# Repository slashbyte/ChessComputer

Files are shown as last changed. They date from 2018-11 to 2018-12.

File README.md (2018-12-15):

# PI Chess Computer
Modeled after the "Chess Challenger" made in 1978.
This PI powered, retro themed build,
is an open source hardware design capable of running an up to date chess engine, Stockfish.

## Raspberry PI Image Release
[Chess Challenger PI Image](https://github.com/slashbyte/ChessComputer-Source/releases)

### Computer Chess Clubs, BEWARE!
(Thats still a thing, right?)

<p align="center">
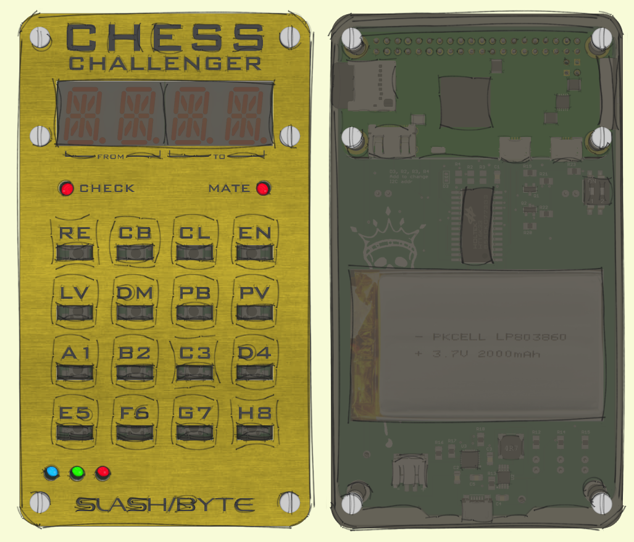
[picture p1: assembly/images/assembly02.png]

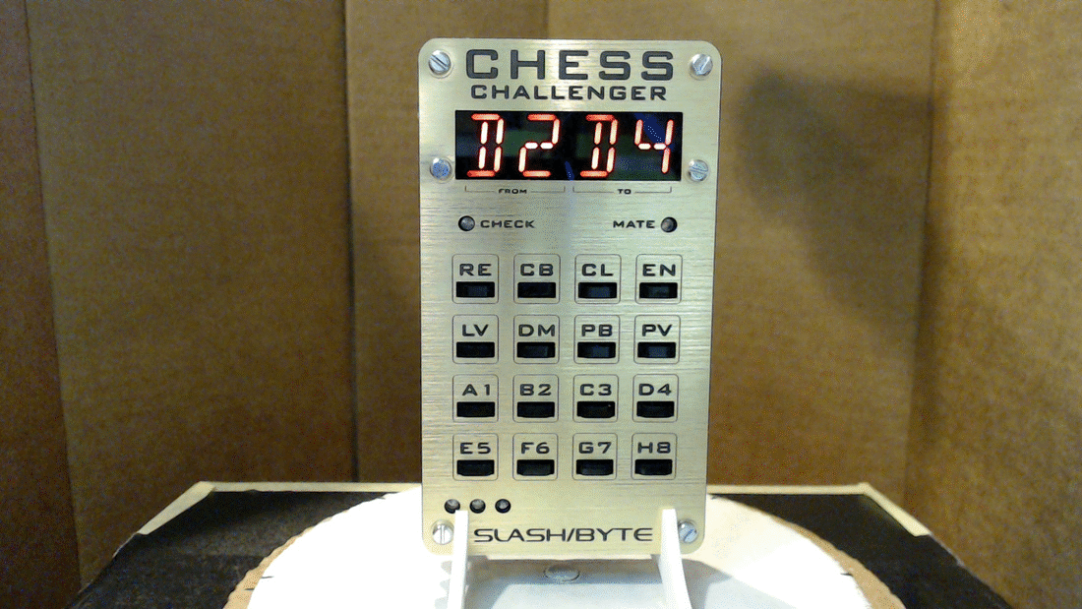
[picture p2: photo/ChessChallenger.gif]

</p>

## Authors
* **Slash/Byte** (slashqpbyte@gmail.com)
## License
This project is licensed under the MIT License
(https://opensource.org/licenses/MIT)
## Acknowledgments
* Science
* Adafruit
* Ponoko (Great fab house)
* Digikey

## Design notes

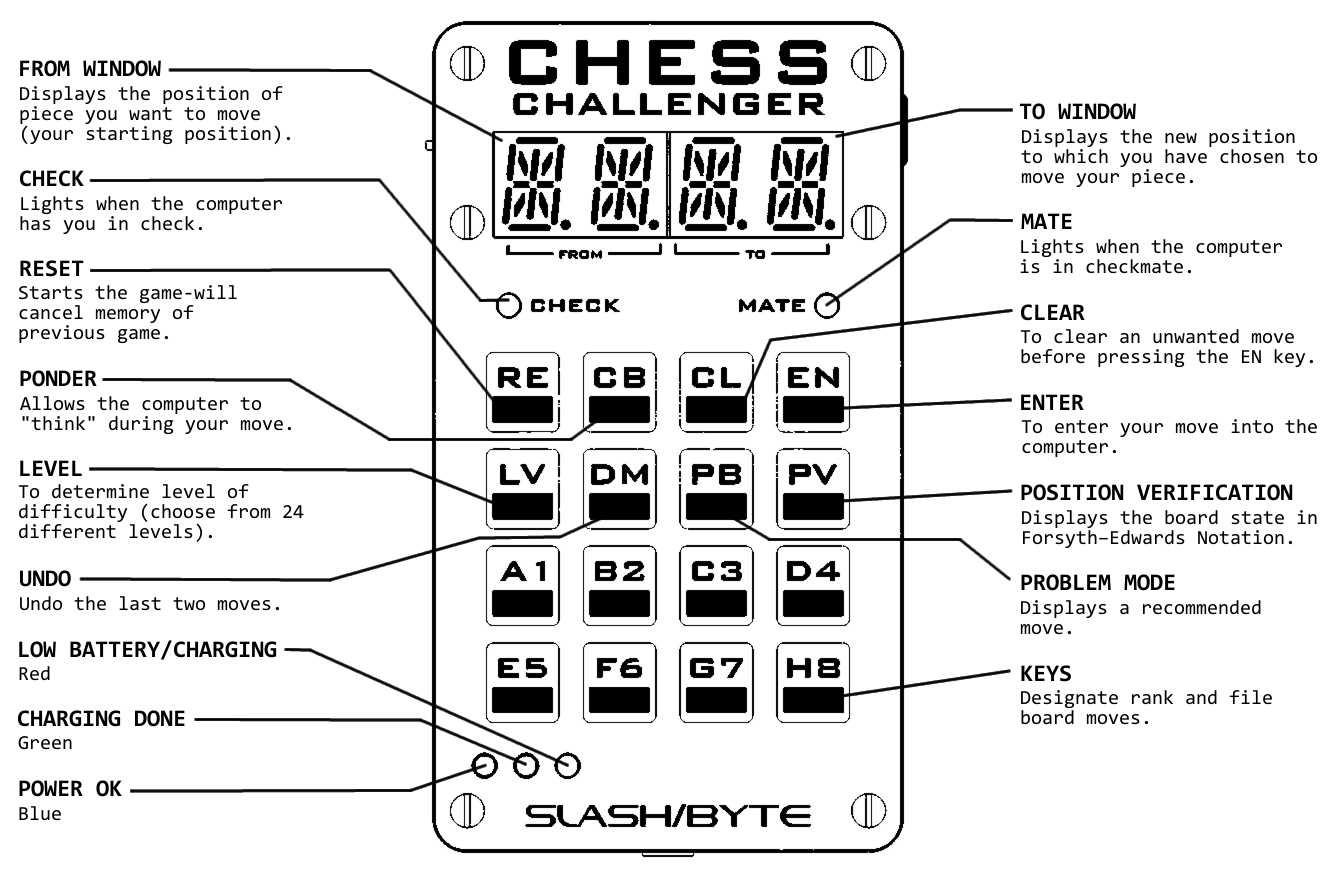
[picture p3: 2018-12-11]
wiki/photo/legned01.png

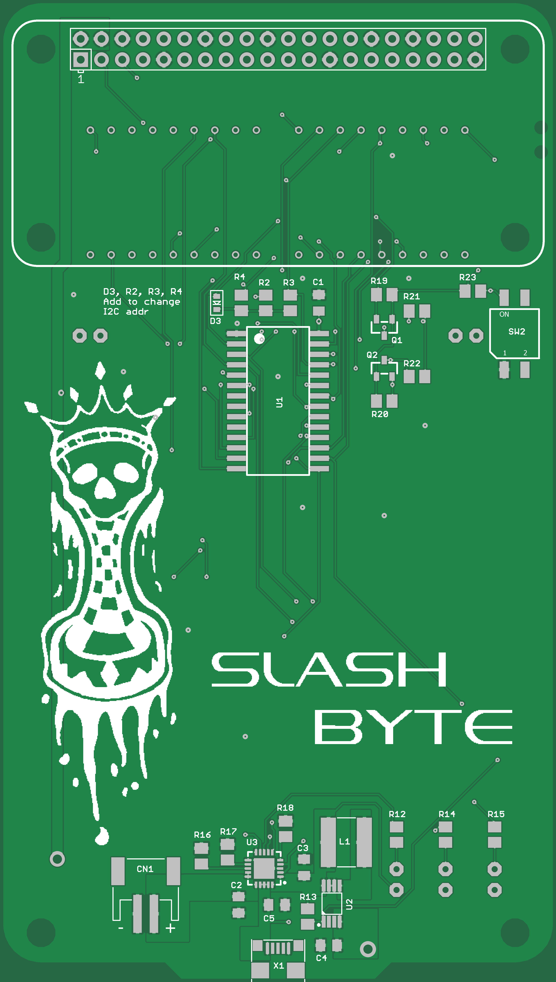
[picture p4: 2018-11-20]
board/eagleUp/eagleUp_ChessComputer_board_bottom.png

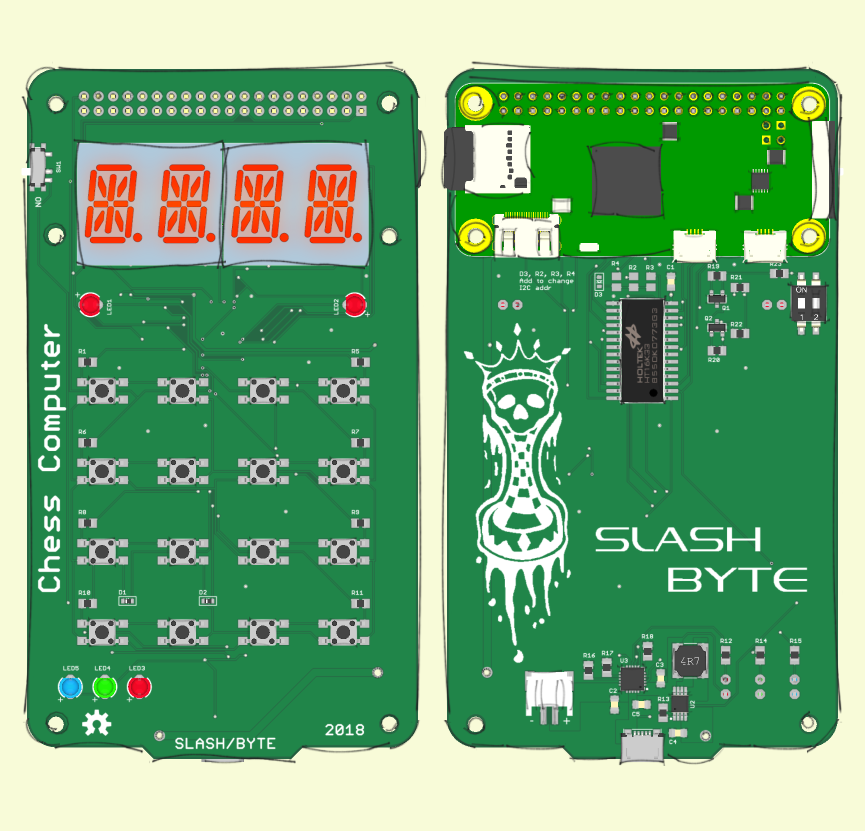
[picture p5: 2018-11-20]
3D render/image.png

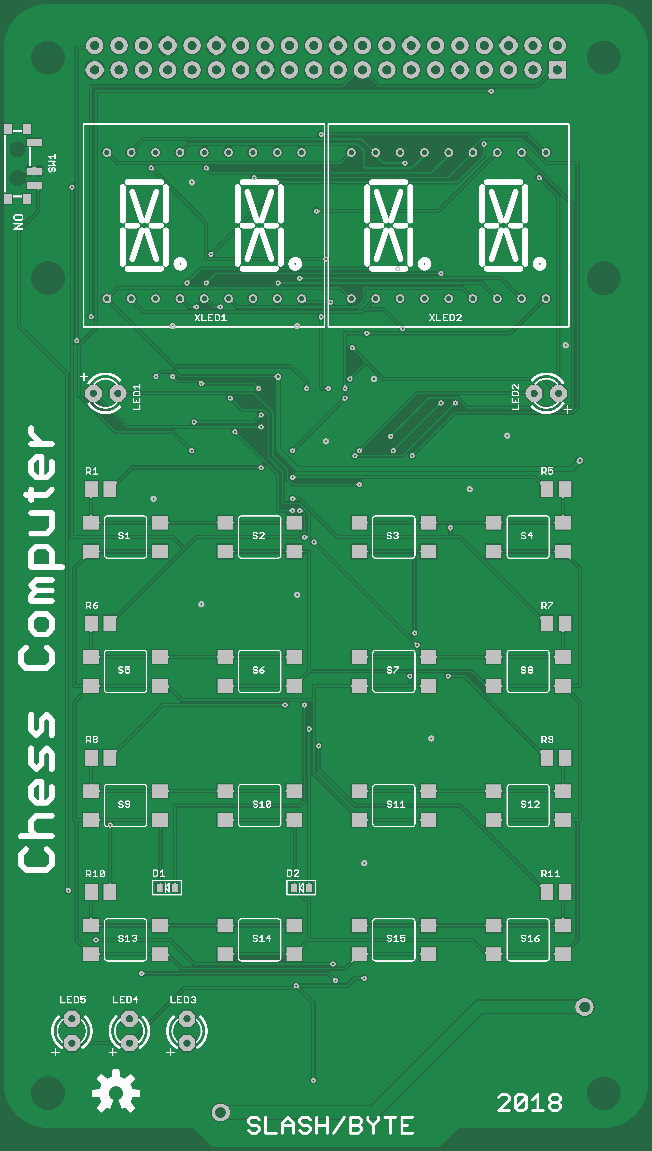
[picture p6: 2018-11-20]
board/eagleUp/eagleUp_ChessComputer_board_top.png

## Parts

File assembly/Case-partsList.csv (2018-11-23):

Index | Quantity | Digikey Part Number | Manufacturer Part Number | Description | Customer Reference
1 | 8 | RPC2275-ND | FW0045A | WASHER FLAT M2 NYLON
2 | 6 | 732-10527-ND | 970070151 | HEX SPACER M2.5X0.45 STEEL 7MM
3 | 4 | RPC4791-ND | R907-2 | ROUND SPACER NYLON 1/8"
4 | 2 | RPC4793-ND | R907-4 | ROUND SPACER NYLON 1/4"
5 | 6 | 36-29306-ND | 29306 | MACH SCREW PAN SLOTTED M2.5X0.45
6 | 6 | 36-29301-ND | 29301 | MACH SCREW PAN SLOTTED M2.5X0.45
7 | 12 | RPC1999-ND | MFW020A | WASHER FLAT M2.5 NYLON | Extra

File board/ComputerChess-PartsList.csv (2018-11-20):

Qty | Value | Device | Package | Parts | Description | Digikey Part Number
1 |  | HT16K33_SOP28 | SOP28_300MIL | U1
1 |  | DIPSWITCH_2PIN | DIPSWITCH_2PIN | SW2 | DIP Switch - 2 Pin | 732-6955-1-ND
1 |  | JST_2PIN-SMT-RA | JST-PH-2-SMT-RA | CN1 | JST 2-Pin Connectors of various flavors | 455-1749-1-ND
1 |  | MICRO-USB_ORIG | DX4R005HJ5 | X1 | SMD micro USB connector | 670-2674-1-ND
1 | 0.1uf | C-USC0805K | C0805K | C1 | CAPACITOR, American symbol | 732-8026-1-ND
1 | 100k | R-US_M0805 | M0805 | R17 | RESISTOR, American symbol | 311-100KCRCT-ND
7 | 10k | R-US_M0805 | M0805 | R13, R18, R19, R20, R21, R22, R23 | RESISTOR, American symbol | A126332CT-ND
4 | 10uf | C-USC0805K | C0805K | C2, C3, C4, C5 | CAPACITOR, American symbol | 732-7620-1-ND
3 | 1N4148 | DIODESOD-523 | SOD-523 | D1, D2, D3 | Diode | 1N4148XTPMSCT-ND
3 | 1k | R-US_M0805 | M0805 | R12, R14, R15 | RESISTOR, American symbol | A106056CT-ND
1 | 2k | R-US_M0805 | M0805 | R16 | RESISTOR, American symbol | 311-2.00KCRCT-ND
1 | 4.7uH | TYS60204R7N-10 | TYS60204R7N-10 | L1 | INDUCTOR | 240-2724-1-ND
11 | 47k | R-US_M0805 | M0805 | R1, R2, R3, R4, R5, R6, R7, R8, R9, R10, R11 | RESISTOR, American symbol | 311-47.0KCRCT-ND
1 | BLUE | LED3MM | LED3MM | LED5 | LED | 732-5011-ND
2 | BSS138 | MOSFET-NREFLOW | SOT23-R | Q1, Q2 | N-Channel Mosfet | BSS138-FDICT-ND
1 | CUS-12TB | SWITCH_SPST | SPST_SMT_19192 | SW1 | Switch - SPST | 563-1102-1-ND
1 | GREEN | LED3MM | LED3MM | LED4 | LED | 732-5012-ND
2 | LTP-3784E | LTP-3784E | TLP-3784E | XLED1, XLED2 | Starburst Display x2 | 160-1010-ND
1 | MCP1642B | MCP1642B | MSOP8 | U2 | MCP1642B | MCP1642B-50I/MS-ND
1 | MCP73871 | MCP73871 | QFN20_4MM | U3 | MCP73871 Lithium Polymer Battery Charger | MCP73871-2AAI/ML-ND
1 | PIZEROW | PIZEROW | RASP_PI_ZERO_BOARD_FULL | PI1 | 40pin Header | 609-4925-ND
3 | RED | LED3MM | LED3MM | LED1, LED2, LED3 | LED | 732-5013-ND
16 | TL3305 | TL3305 | TL3305 | S1, S2, S3, S4, S5, S6, S7, S8, S9, S10, S11, S12, S13, S14, S15, S16 | Switch (5mm board height) | EG5354CT-ND
1 | 3.7v @ 2AH | LIPO | JST-PH-2 |  | 3.7V Lithium-Ion Battery Rechargeable (Secondary) 2Ah | 1528-1857-ND

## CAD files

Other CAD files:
3D render/pcb.skp
assembly/case.skp

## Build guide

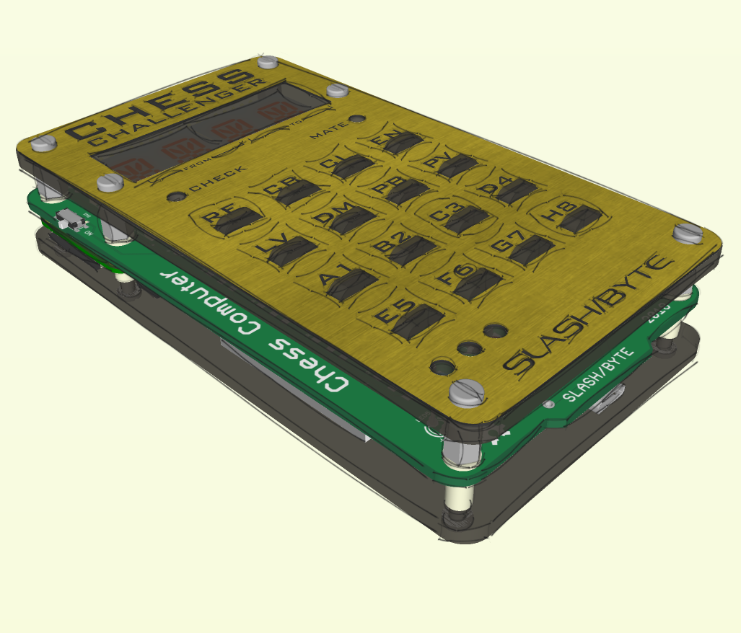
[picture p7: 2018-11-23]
assembly/images/assembly01.png

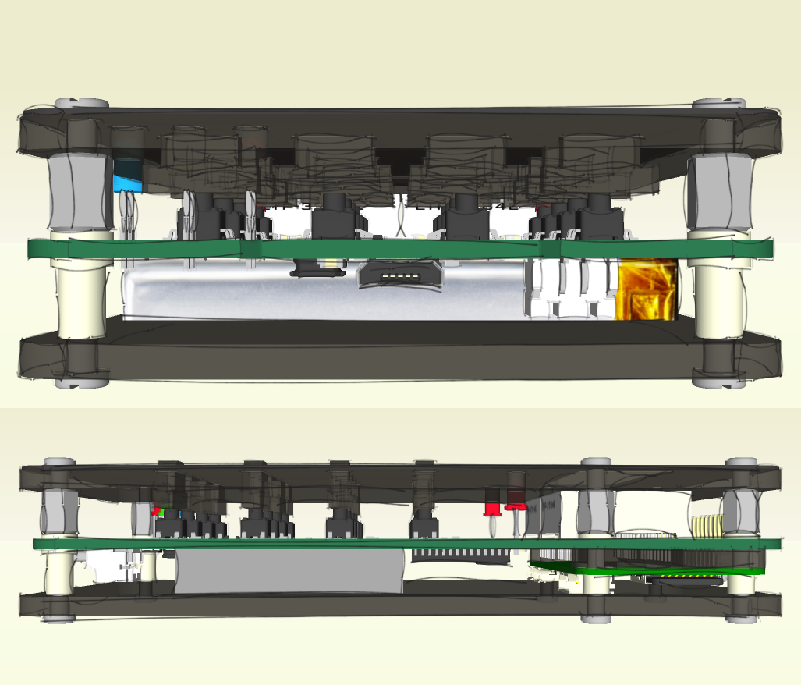
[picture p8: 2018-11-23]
assembly/images/assembly03.png

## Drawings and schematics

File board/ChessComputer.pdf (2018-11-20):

A

A

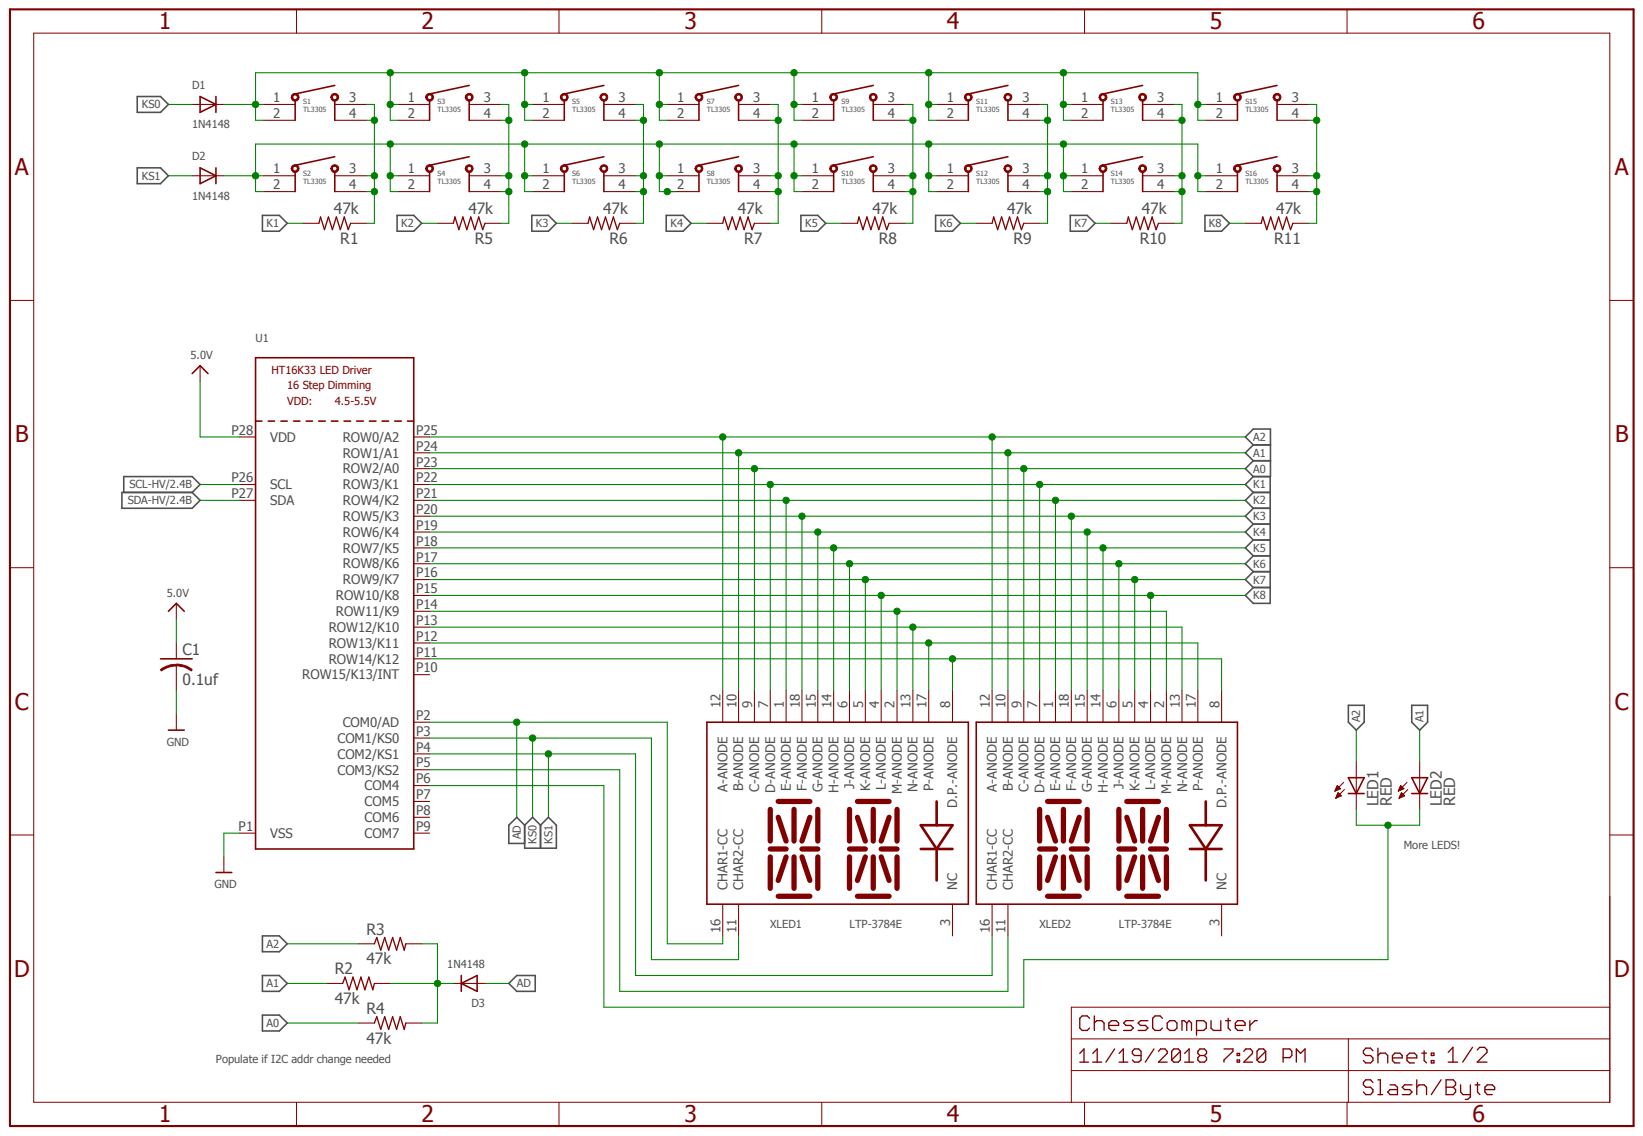
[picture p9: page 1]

Populate if I2C addr change needed

A

A

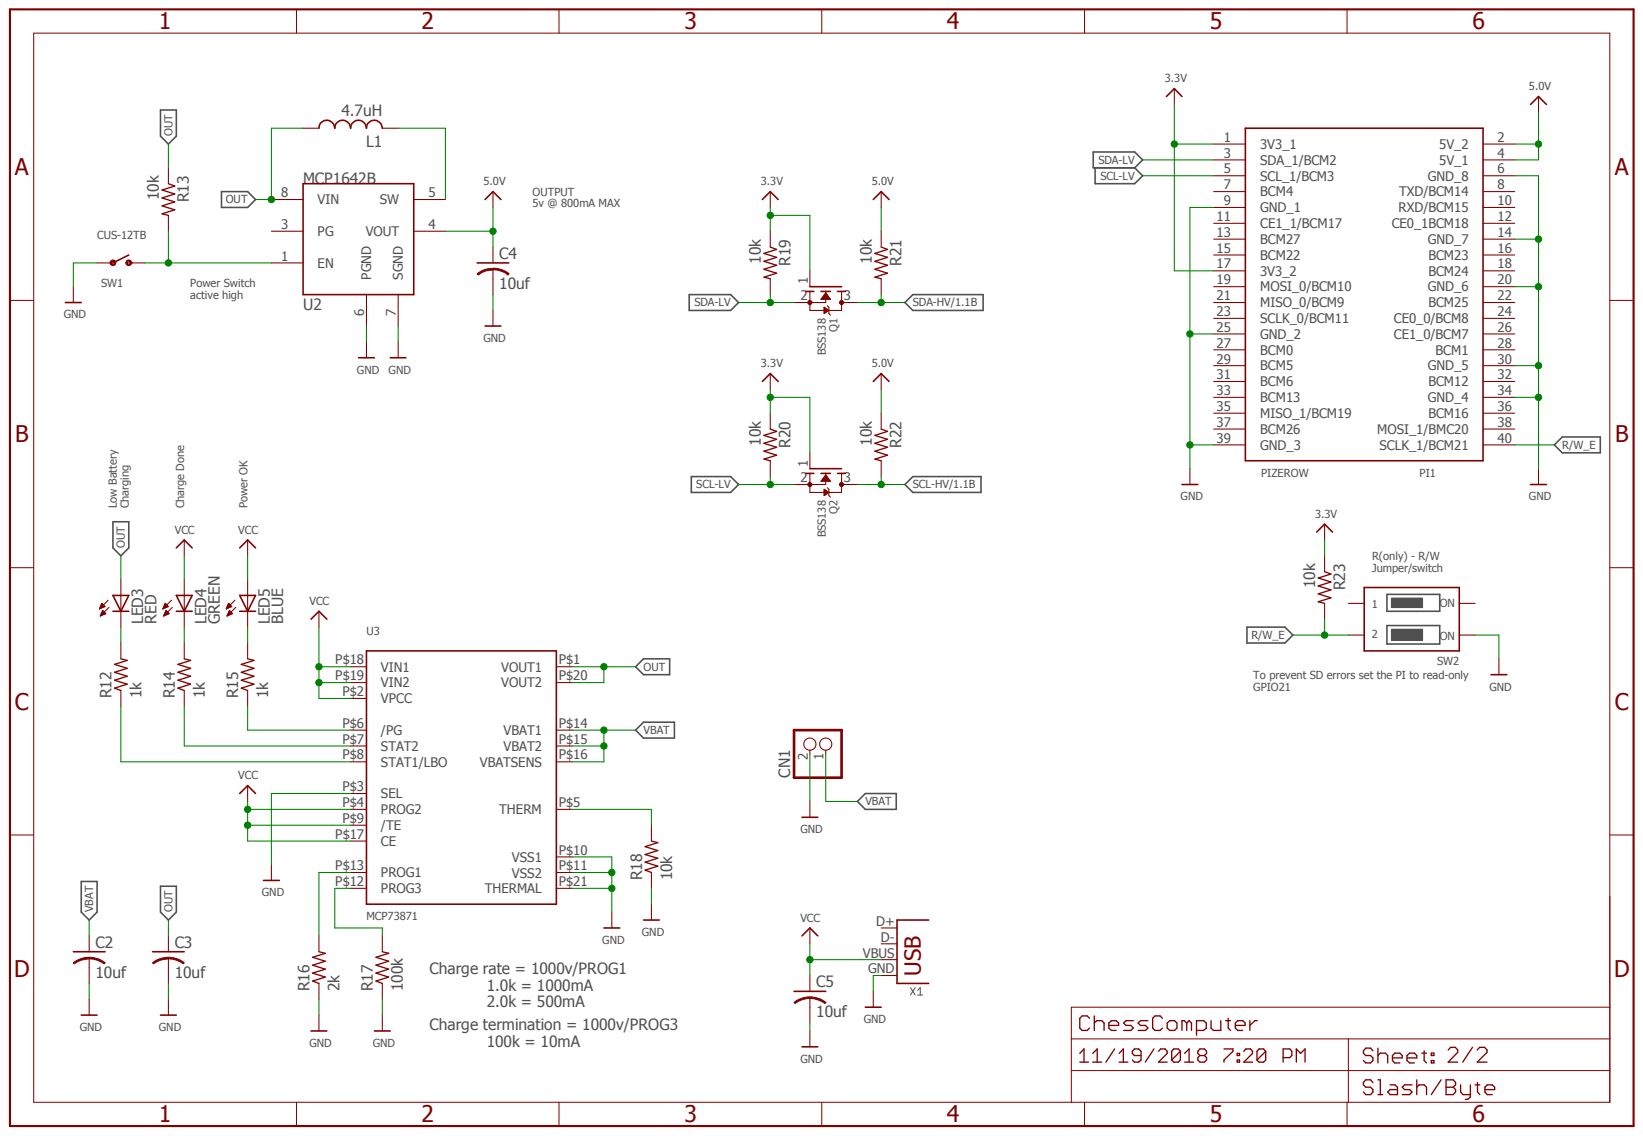
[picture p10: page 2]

To prevent SD errors set the PI to read-only
GPIO21

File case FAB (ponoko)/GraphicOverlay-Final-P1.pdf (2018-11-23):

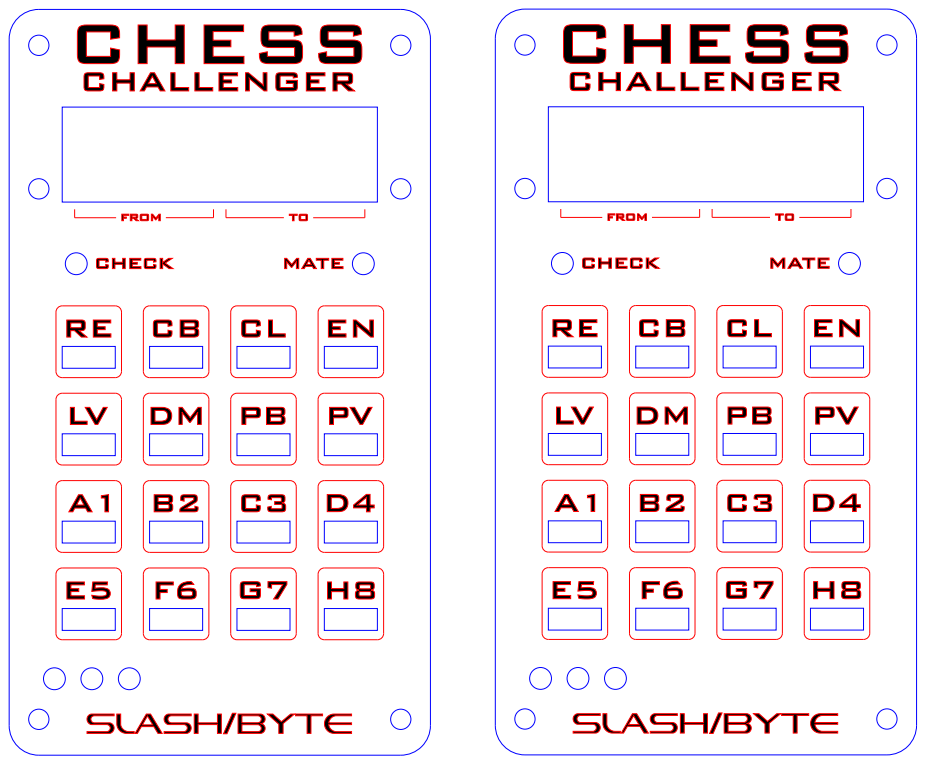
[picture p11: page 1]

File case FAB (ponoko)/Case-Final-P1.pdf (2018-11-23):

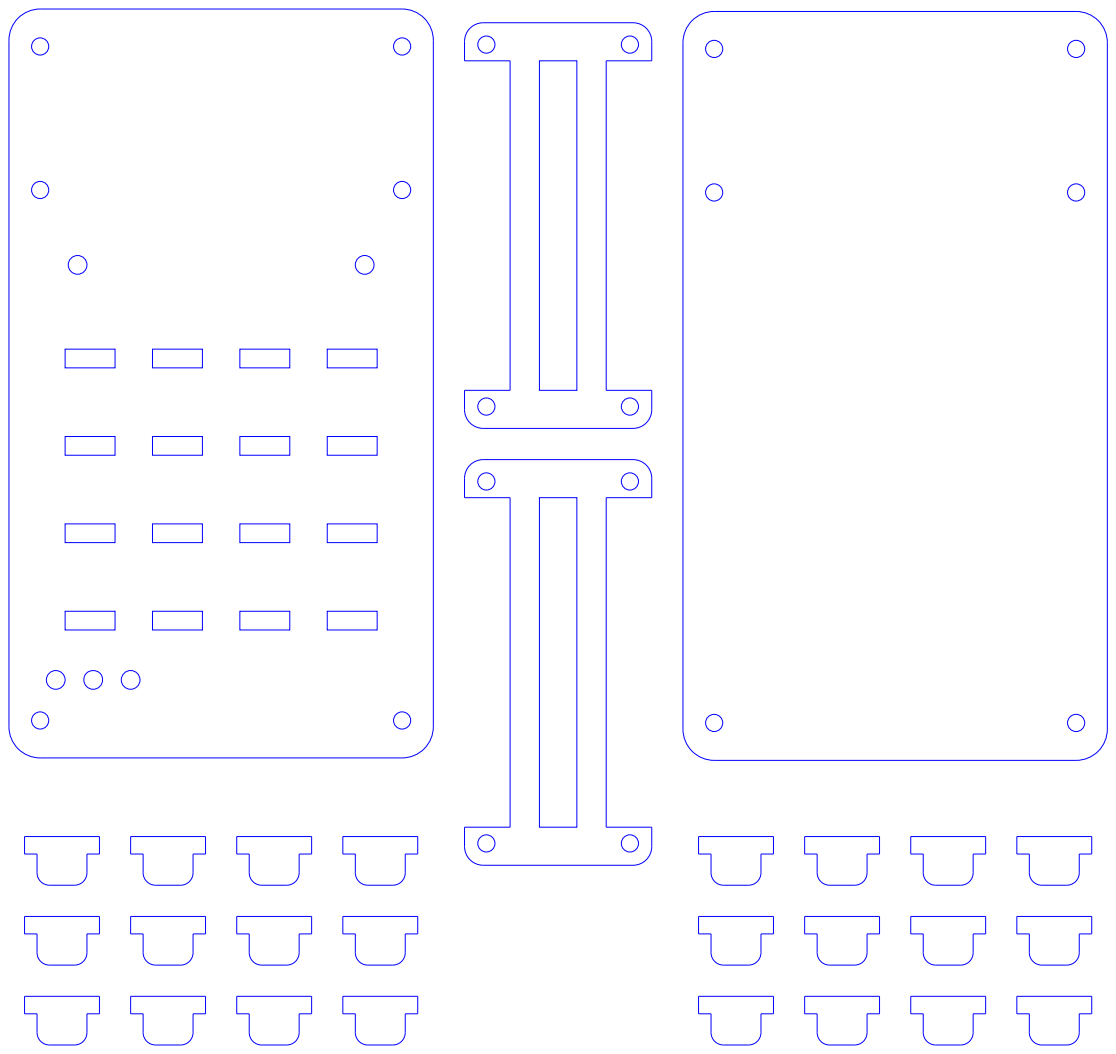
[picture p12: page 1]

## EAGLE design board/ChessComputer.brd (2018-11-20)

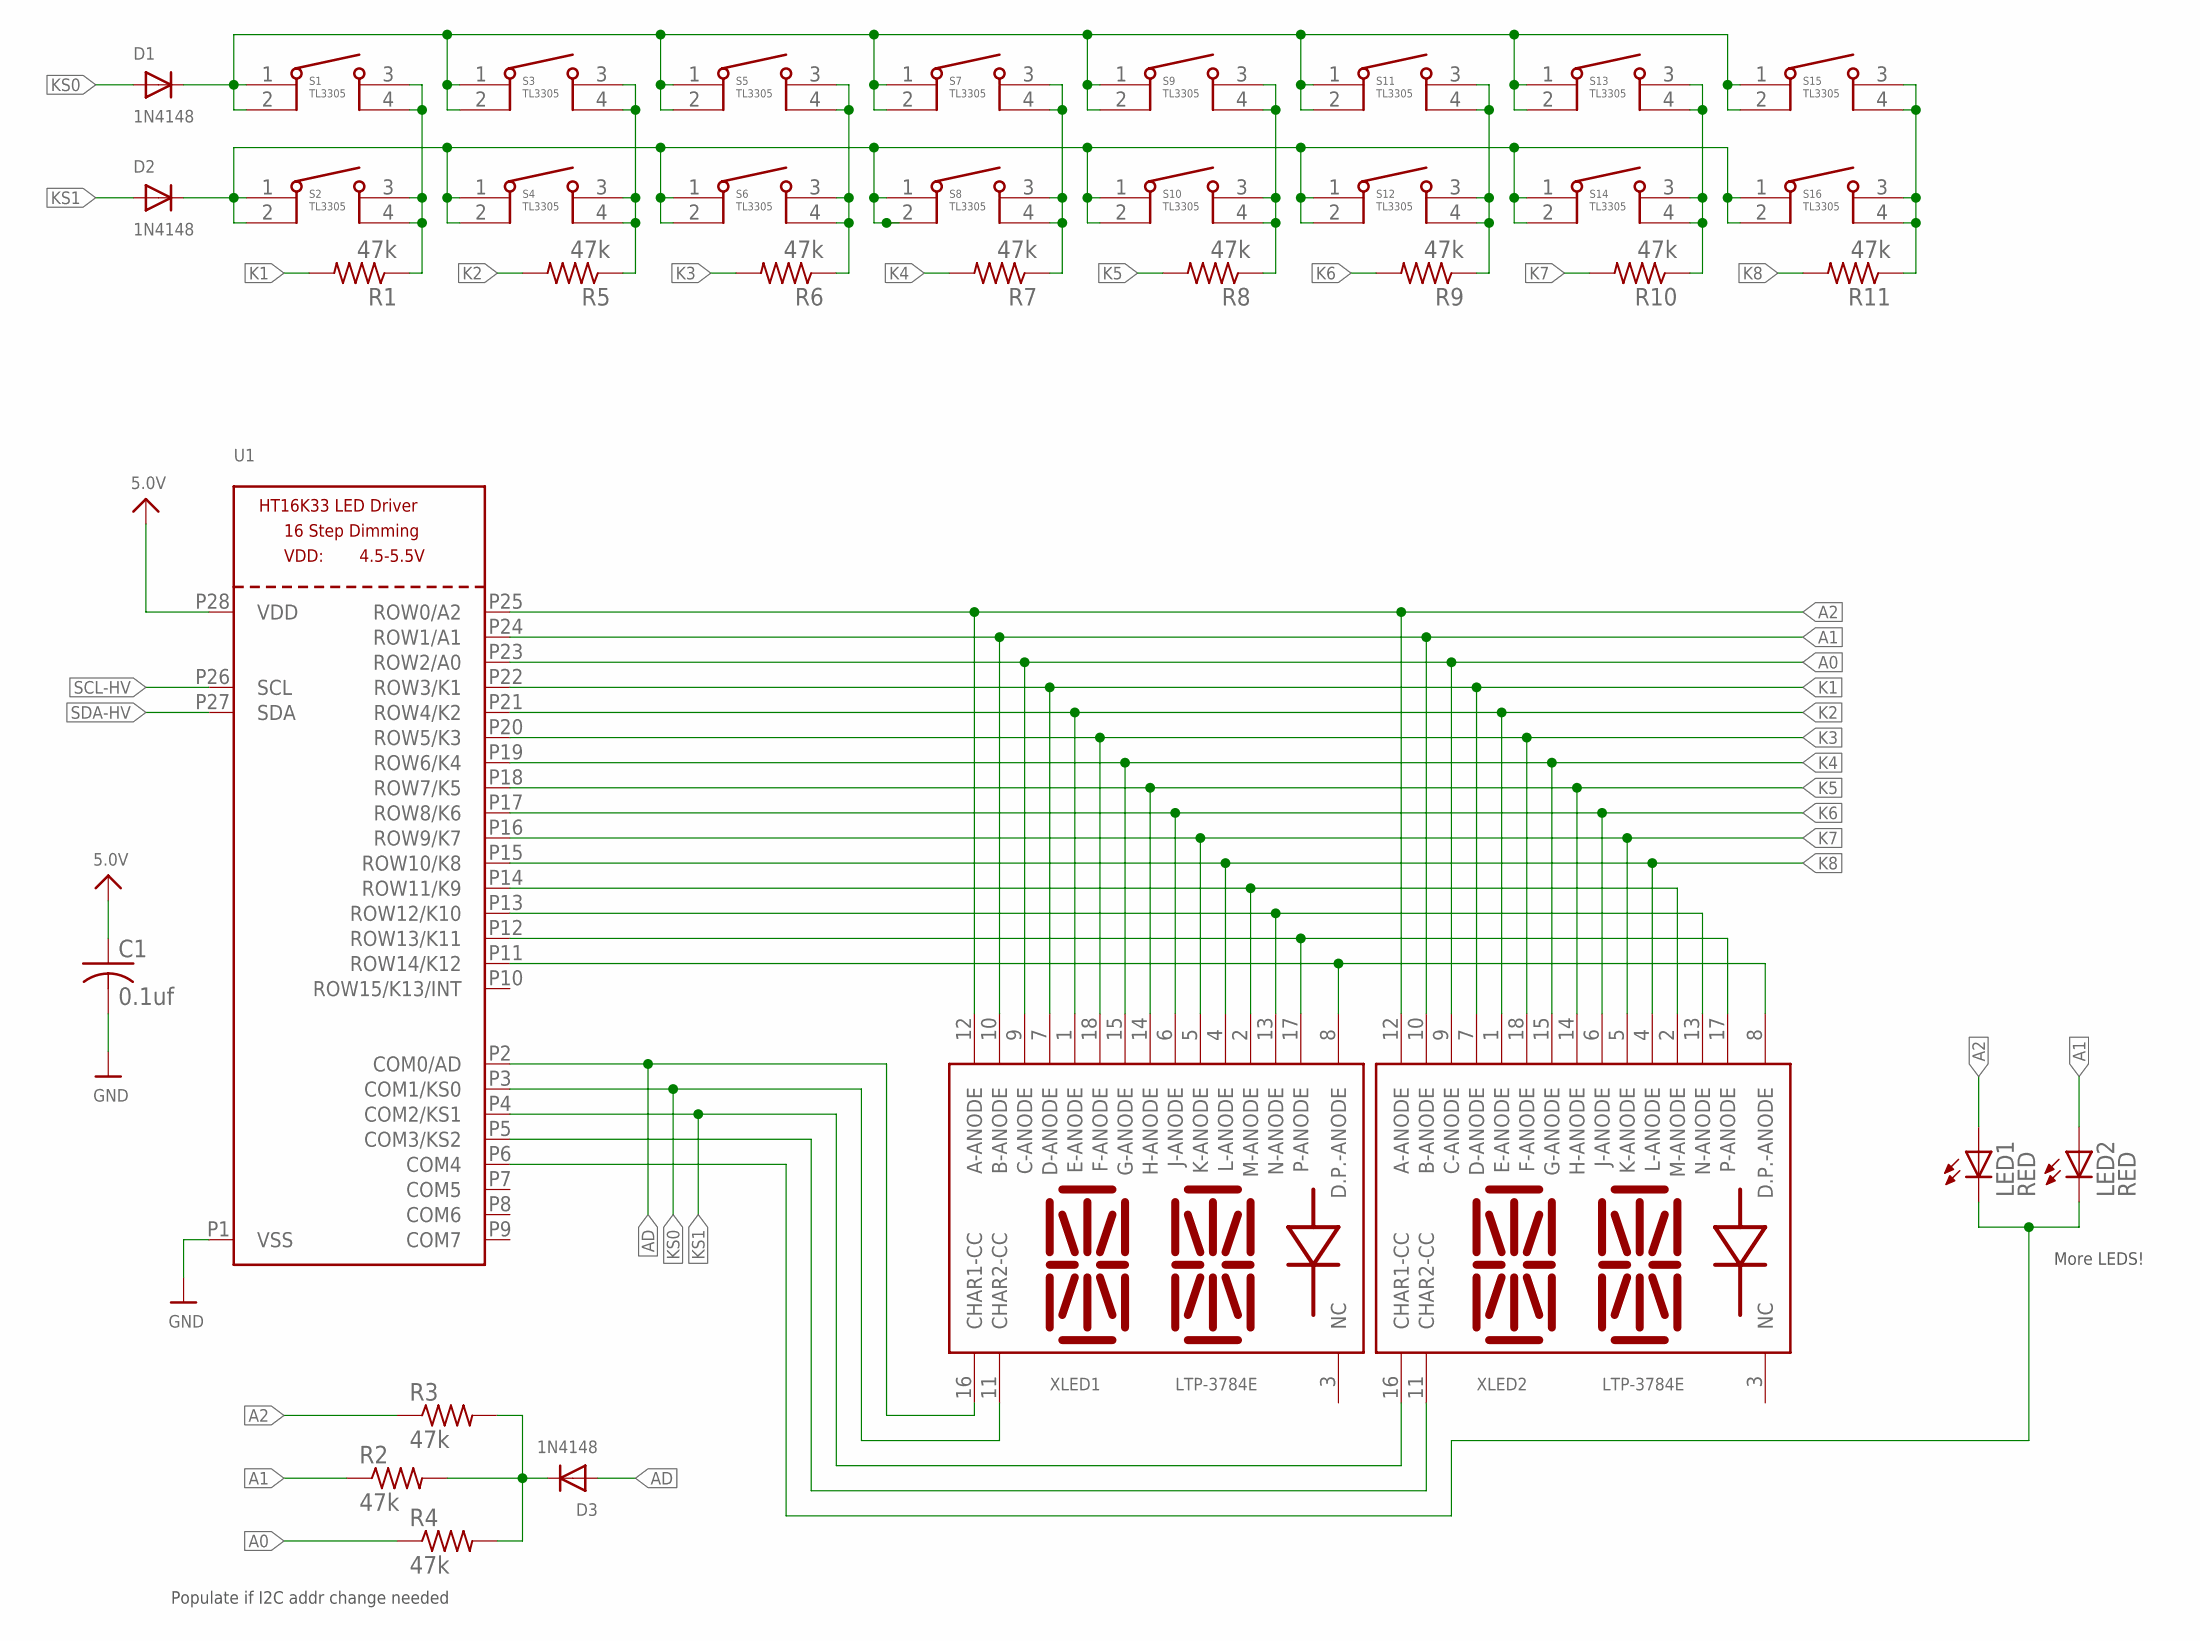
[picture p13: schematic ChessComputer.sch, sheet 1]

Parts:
C1: 0.1uf; C0805K
D1, D2, D3: 1N4148; SOD-523
LED1, LED2: RED; LED3MM
R1, R2, R3, R4, R5, R6, R7, R8, R9, R10, R11: 47k; M0805
S1, S2, S3, S4, S5, S6, S7, S8, S9, S10, S11, S12, S13, S14, S15, S16: TL3305
U1: HT16K33_SOP28; SOP28_300MIL
XLED1, XLED2: LTP-3784E; TLP-3784E

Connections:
5.0V: C1.1, U1.P28 (VDD); also elsewhere on the board
A0: R4.1, U1.P23 (ROW2/A0), XLED1.9 (C-ANODE), XLED2.9 (C-ANODE)
A1: LED2.A, R2.1, U1.P24 (ROW1/A1), XLED1.10 (B-ANODE), XLED2.10 (B-ANODE)
A2: LED1.A, R3.1, U1.P25 (ROW0/A2), XLED1.12 (A-ANODE), XLED2.12 (A-ANODE)
AD: D3.A, U1.P2 (COM0/AD), XLED1.16 (CHAR1-CC)
GND: C1.2, U1.P1 (VSS); also elsewhere on the board
K1: R1.2, U1.P22 (ROW3/K1), XLED1.7 (D-ANODE), XLED2.7 (D-ANODE)
K2: R5.2, U1.P21 (ROW4/K2), XLED1.1 (E-ANODE), XLED2.1 (E-ANODE)
K3: R6.2, U1.P20 (ROW5/K3), XLED1.18 (F-ANODE), XLED2.18 (F-ANODE)
K4: R7.2, U1.P19 (ROW6/K4), XLED1.15 (G-ANODE), XLED2.15 (G-ANODE)
K5: R8.2, U1.P18 (ROW7/K5), XLED1.14 (H-ANODE), XLED2.14 (H-ANODE)
K6: R9.2, U1.P17 (ROW8/K6), XLED1.6 (J-ANODE), XLED2.6 (J-ANODE)
K7: R10.2, U1.P16 (ROW9/K7), XLED1.5 (K-ANODE), XLED2.5 (K-ANODE)
K8: R11.2, U1.P15 (ROW10/K8), XLED1.4 (L-ANODE), XLED2.4 (L-ANODE)
KS0: D1.A, U1.P3 (COM1/KS0), XLED1.11 (CHAR2-CC)
KS1: D2.A, U1.P4 (COM2/KS1), XLED2.16 (CHAR1-CC)
unnamed: LED1.K (C), LED2.K (C), U1.P6 (COM4)
unnamed: U1.P14 (ROW11/K9), XLED1.2 (M-ANODE), XLED2.2 (M-ANODE)
unnamed: U1.P13 (ROW12/K10), XLED1.13 (N-ANODE), XLED2.13 (N-ANODE)
unnamed: U1.P12 (ROW13/K11), XLED1.17 (P-ANODE), XLED2.17 (P-ANODE)
unnamed: U1.P11 (ROW14/K12), XLED1.8 (D.P.-ANODE), XLED2.8 (D.P.-ANODE)
unnamed: D2.K (C), S2.1, S2.2, S4.1, S4.2, S6.1, S6.2, S8.1, S8.2, S10.1, S10.2, S12.1, S12.2, S14.1, S14.2, S16.1, S16.2
unnamed: U1.P5 (COM3/KS2), XLED2.11 (CHAR2-CC)
unnamed: D3.K (C), R2.2, R3.2, R4.2
unnamed: R1.1, S1.3, S1.4, S2.3, S2.4
unnamed: R5.1, S3.3, S3.4, S4.3, S4.4
unnamed: R6.1, S5.3, S5.4, S6.3, S6.4
unnamed: R7.1, S7.3, S7.4, S8.3, S8.4
unnamed: R8.1, S9.3, S9.4, S10.3, S10.4
unnamed: R9.1, S11.3, S11.4, S12.3, S12.4
unnamed: D1.K (C), S1.1, S1.2, S3.1, S3.2, S5.1, S5.2, S7.1, S7.2, S9.1, S9.2, S11.1, S11.2, S13.1, S13.2, S15.1, S15.2
unnamed: R10.1, S13.3, S13.4, S14.3, S14.4
unnamed: R11.1, S15.3, S15.4, S16.3, S16.4
SCL-HV: U1.P26 (SCL); also elsewhere on the board
SDA-HV: U1.P27 (SDA); also elsewhere on the board

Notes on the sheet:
More LEDS!
Populate if I2C addr change needed

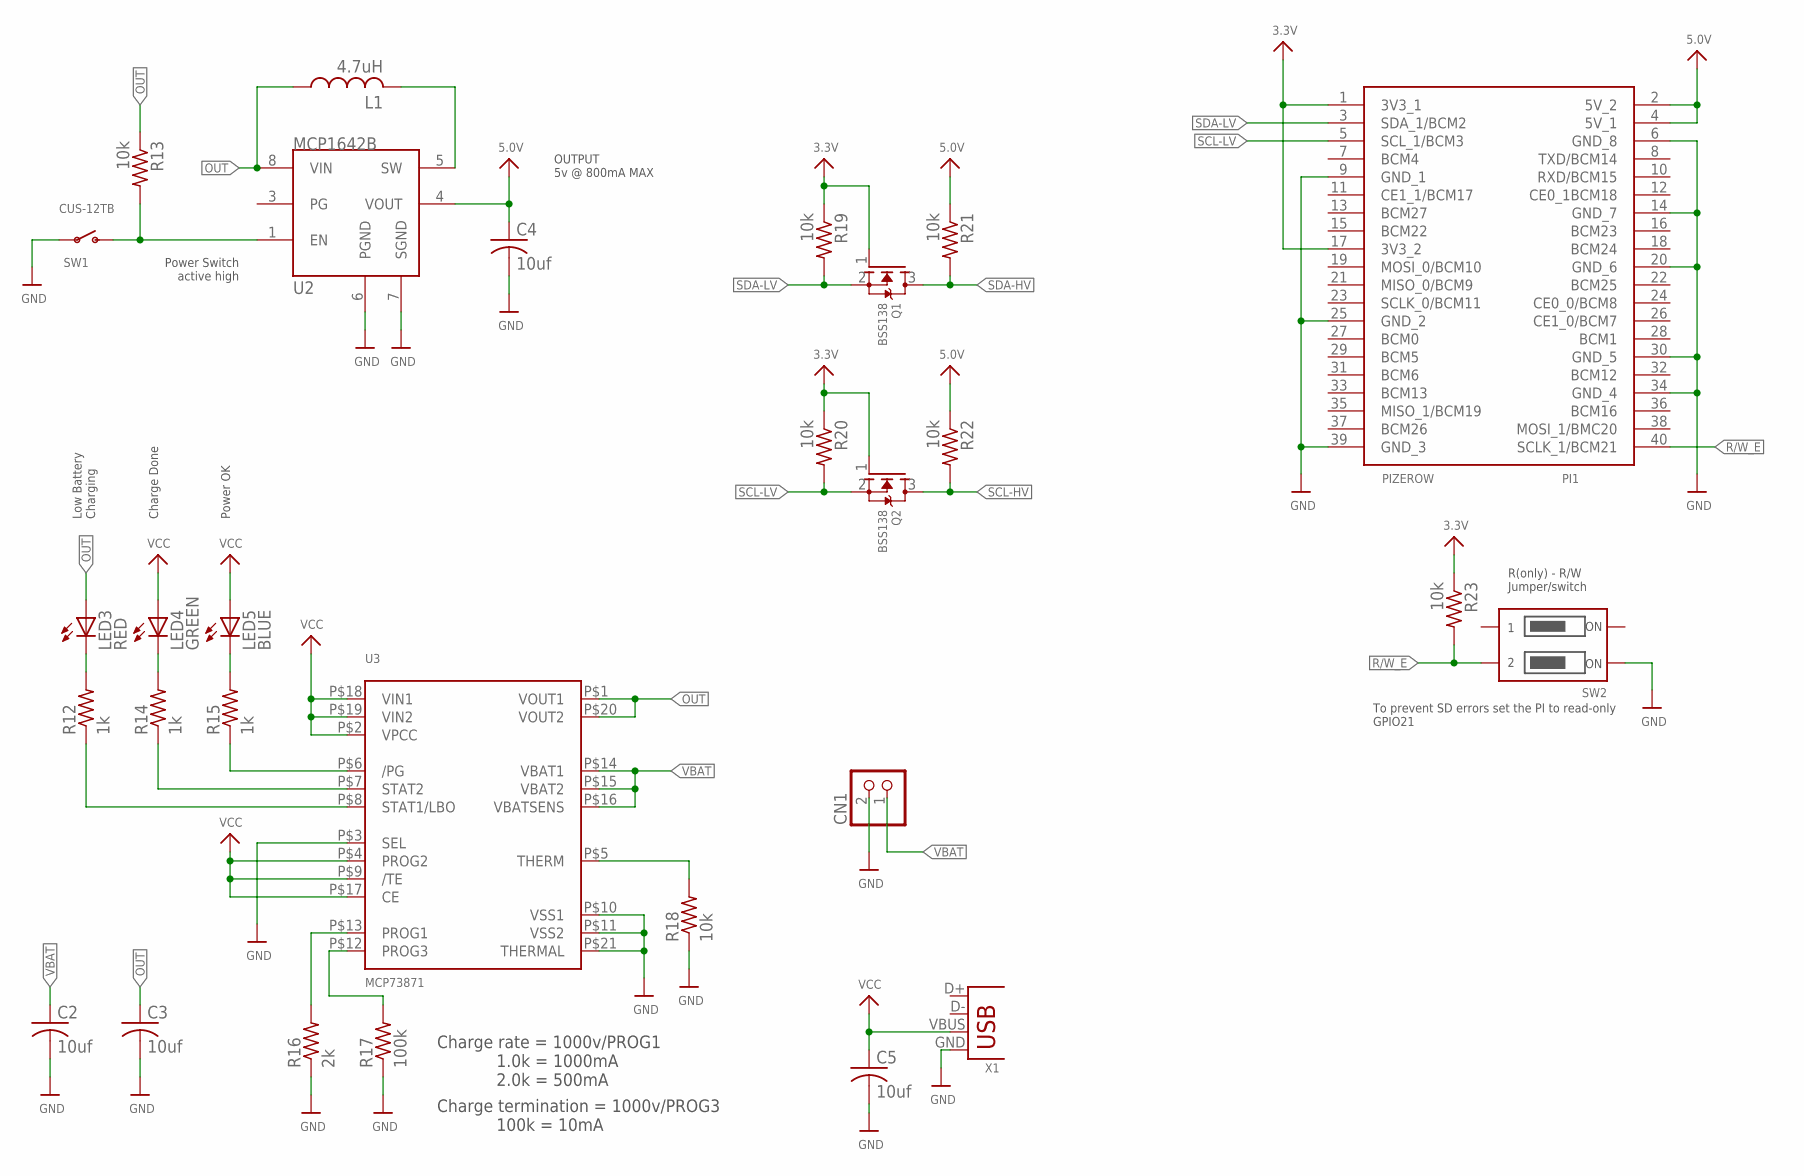
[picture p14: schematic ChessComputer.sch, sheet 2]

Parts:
C2, C3, C4, C5: 10uf; C0805K
CN1: JST_2PIN-SMT-RA; JST-PH-2-SMT-RA
L1: 4.7uH; TYS60204R7N-10
LED3: RED; LED3MM
LED4: GREEN; LED3MM
LED5: BLUE; LED3MM
PI1: PIZEROW; RASP_PI_ZERO_BOARD_FULL
Q1, Q2: BSS138; SOT23-R
R12, R14, R15: 1k; M0805
R13, R18, R19, R20, R21, R22, R23: 10k; M0805
R16: 2k; M0805
R17: 100k; M0805
SW1: CUS-12TB; SPST_SMT_19192
SW2: DIPSWITCH_2PIN
U2: MCP1642B; MSOP8
U3: MCP73871; QFN20_4MM
X1: MICRO-USB_ORIG; DX4R005HJ5

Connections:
3.3V: PI1.1 (3V3_1), PI1.17 (3V3_2), Q1.1 (G), Q2.1 (G), R19.1, R20.1, R23.1
5.0V: C4.1, PI1.2 (5V_2), PI1.4 (5V_1), R21.1, R22.1, U2.4 (VOUT); also elsewhere on the board
ENABLE: R13.2, SW1.C (S), U2.1 (EN)
GND: C2.2, C3.2, C4.2, C5.2, CN1.2 (1), PI1.6 (GND_8), PI1.9 (GND_1), PI1.14 (GND_7), PI1.20 (GND_6), PI1.25 (GND_2), PI1.30 (GND_5), PI1.34 (GND_4), PI1.39 (GND_3), R16.1, R17.1, R18.1, SW1.B, SW2.1A, U2.6 (PGND), U2.7 (SGND), U3.P$3 (SEL), U3.P$10 (VSS1), U3.P$11 (VSS2), U3.P$21 (THERMAL), X1.GND; also elsewhere on the board
unnamed: R18.2, U3.P$5 (THERM)
unnamed: R17.2, U3.P$12 (PROG3)
unnamed: R16.2, U3.P$13 (PROG1)
unnamed: L1.P$2 (2), U2.5 (SW)
unnamed: R15.1, U3.P$6 (/PG)
unnamed: LED5.K (C), R15.2
unnamed: LED4.K (C), R14.2
unnamed: LED3.K (C), R12.2
unnamed: R14.1, U3.P$7 (STAT2)
unnamed: R12.1, U3.P$8 (STAT1/LBO)
OUT: C3.1, L1.P$1 (1), LED3.A, R13.1, U2.8 (VIN), U3.P$1 (VOUT1), U3.P$20 (VOUT2)
R/W_E: PI1.40 (SCLK_1/BCM21), R23.2, SW2.1B
SCL-HV: Q2.3 (D), R22.2; also elsewhere on the board
SCL-LV: PI1.5 (SCL_1/BCM3), Q2.2 (S), R20.2
SDA-HV: Q1.3 (D), R21.2; also elsewhere on the board
SDA-LV: PI1.3 (SDA_1/BCM2), Q1.2 (S), R19.2
VBAT: C2.1, CN1.1 (2), U3.P$14 (VBAT1), U3.P$15 (VBAT2), U3.P$16 (VBATSENS)
VCC: C5.1, LED4.A, LED5.A, U3.P$2 (VPCC), U3.P$4 (PROG2), U3.P$9 (/TE), U3.P$17 (CE), U3.P$18 (VIN1), U3.P$19 (VIN2), X1.VBUS

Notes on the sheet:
Charge rate = 1000v/PROG1 1.0k = 1000mA 2.0k = 500mA
Charge termination = 1000v/PROG3 100k = 10mA
Low Battery Charging
Charge Done
Power OK
Power Switch active high
OUTPUT 5v @ 800mA MAX
R(only) - R/W Jumper/switch
To prevent SD errors set the PI to read-only GPIO21

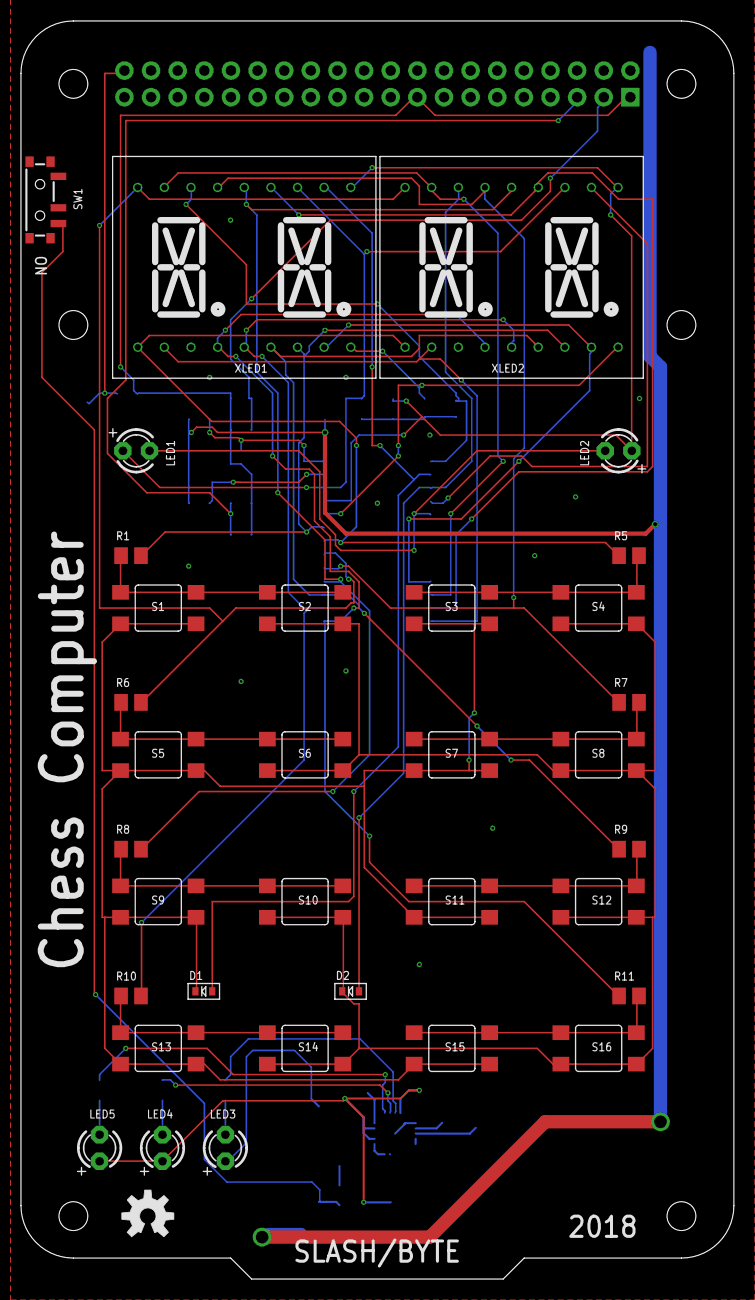
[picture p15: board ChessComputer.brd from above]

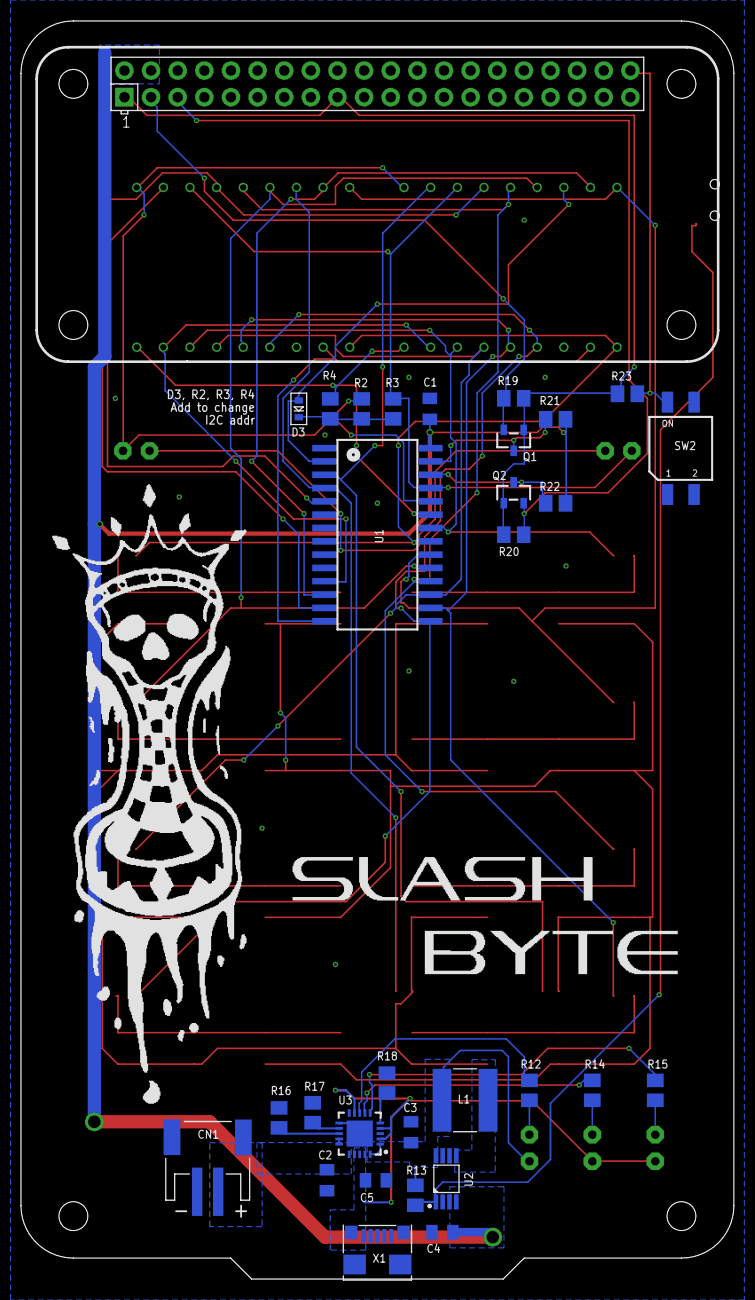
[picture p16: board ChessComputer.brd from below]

Board: 2 copper layers, 68.0 x 120.0 mm, 68 parts (33 on the bottom side), 53 nets.

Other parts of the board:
U$1: OSHW-LOGO-M
U$2: CHESSLOGO1
U$3: SLASHBYTE

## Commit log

2018-11-20 added some stuff
    work in progress
    [ChessComputer.brd, ChessComputer.sch, ComputerChess-PartsList.xlsx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]
2018-11-20 no comment
    [ComputerChess-PartsList.csv]
2018-11-23 case design
    kablam!
    [Case-partsList.csv, case.skp, pcb.skp]
2018-11-30 fixed check led
    DP was being overwriten or something, idk, it was buggin me.
2018-12-02 assembly exploded
    added an exploded assembly guide

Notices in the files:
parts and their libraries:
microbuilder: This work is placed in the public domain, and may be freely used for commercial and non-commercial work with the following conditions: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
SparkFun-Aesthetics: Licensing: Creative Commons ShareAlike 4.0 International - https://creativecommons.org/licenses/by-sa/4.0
